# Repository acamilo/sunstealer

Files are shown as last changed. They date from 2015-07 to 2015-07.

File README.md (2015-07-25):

## SunStealer

Sunstealer is a 15 watt single color (rs485) networked LED strip built using a LT34781 driver and a PIC32MX110F016B. These strips are intended to be used to build larger LED panels with each strip covering a specific wavelength.

The goal is to be able to control the amount of light received by plants at each of these wavelengths and attempt to replicate some of the existing studies on type of light and it's affect on vegetative growth and fruiting.

There will be 5 variants of the strip each populated with LEDs targeting te following wavelengths (439,469,642,667,740) initially with the following ratios (1,1,2,2,1) This should make 1 105w LED light for hydro/aquaponics.

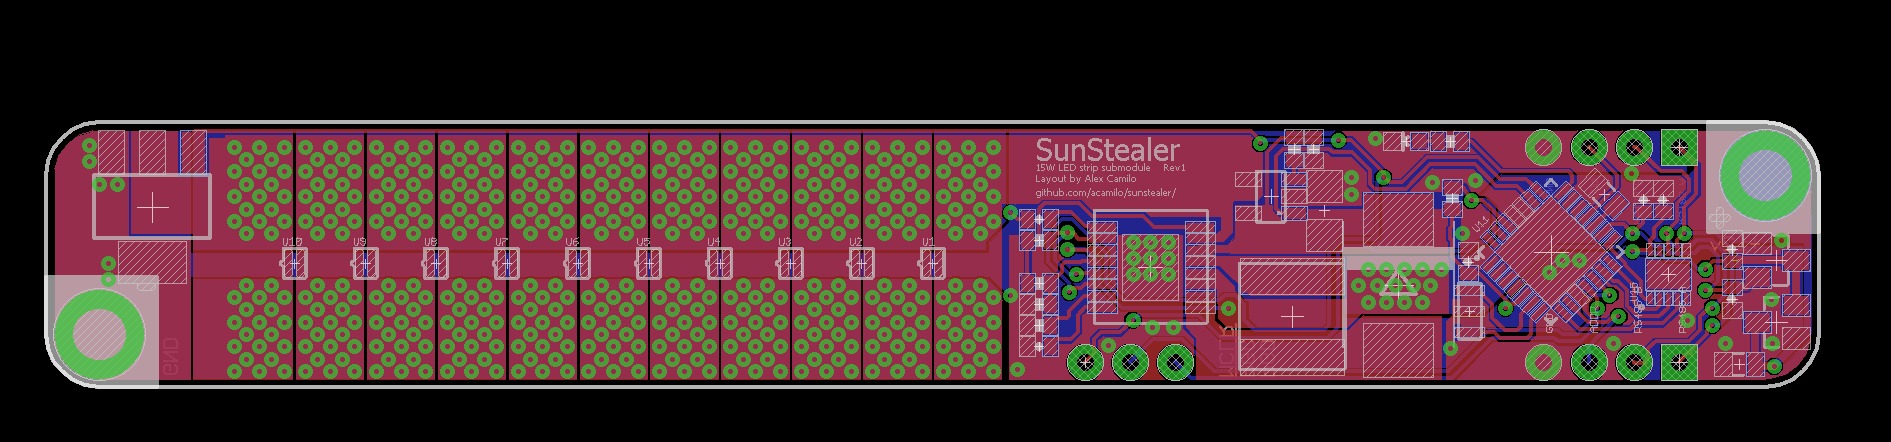
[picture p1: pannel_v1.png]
pcb


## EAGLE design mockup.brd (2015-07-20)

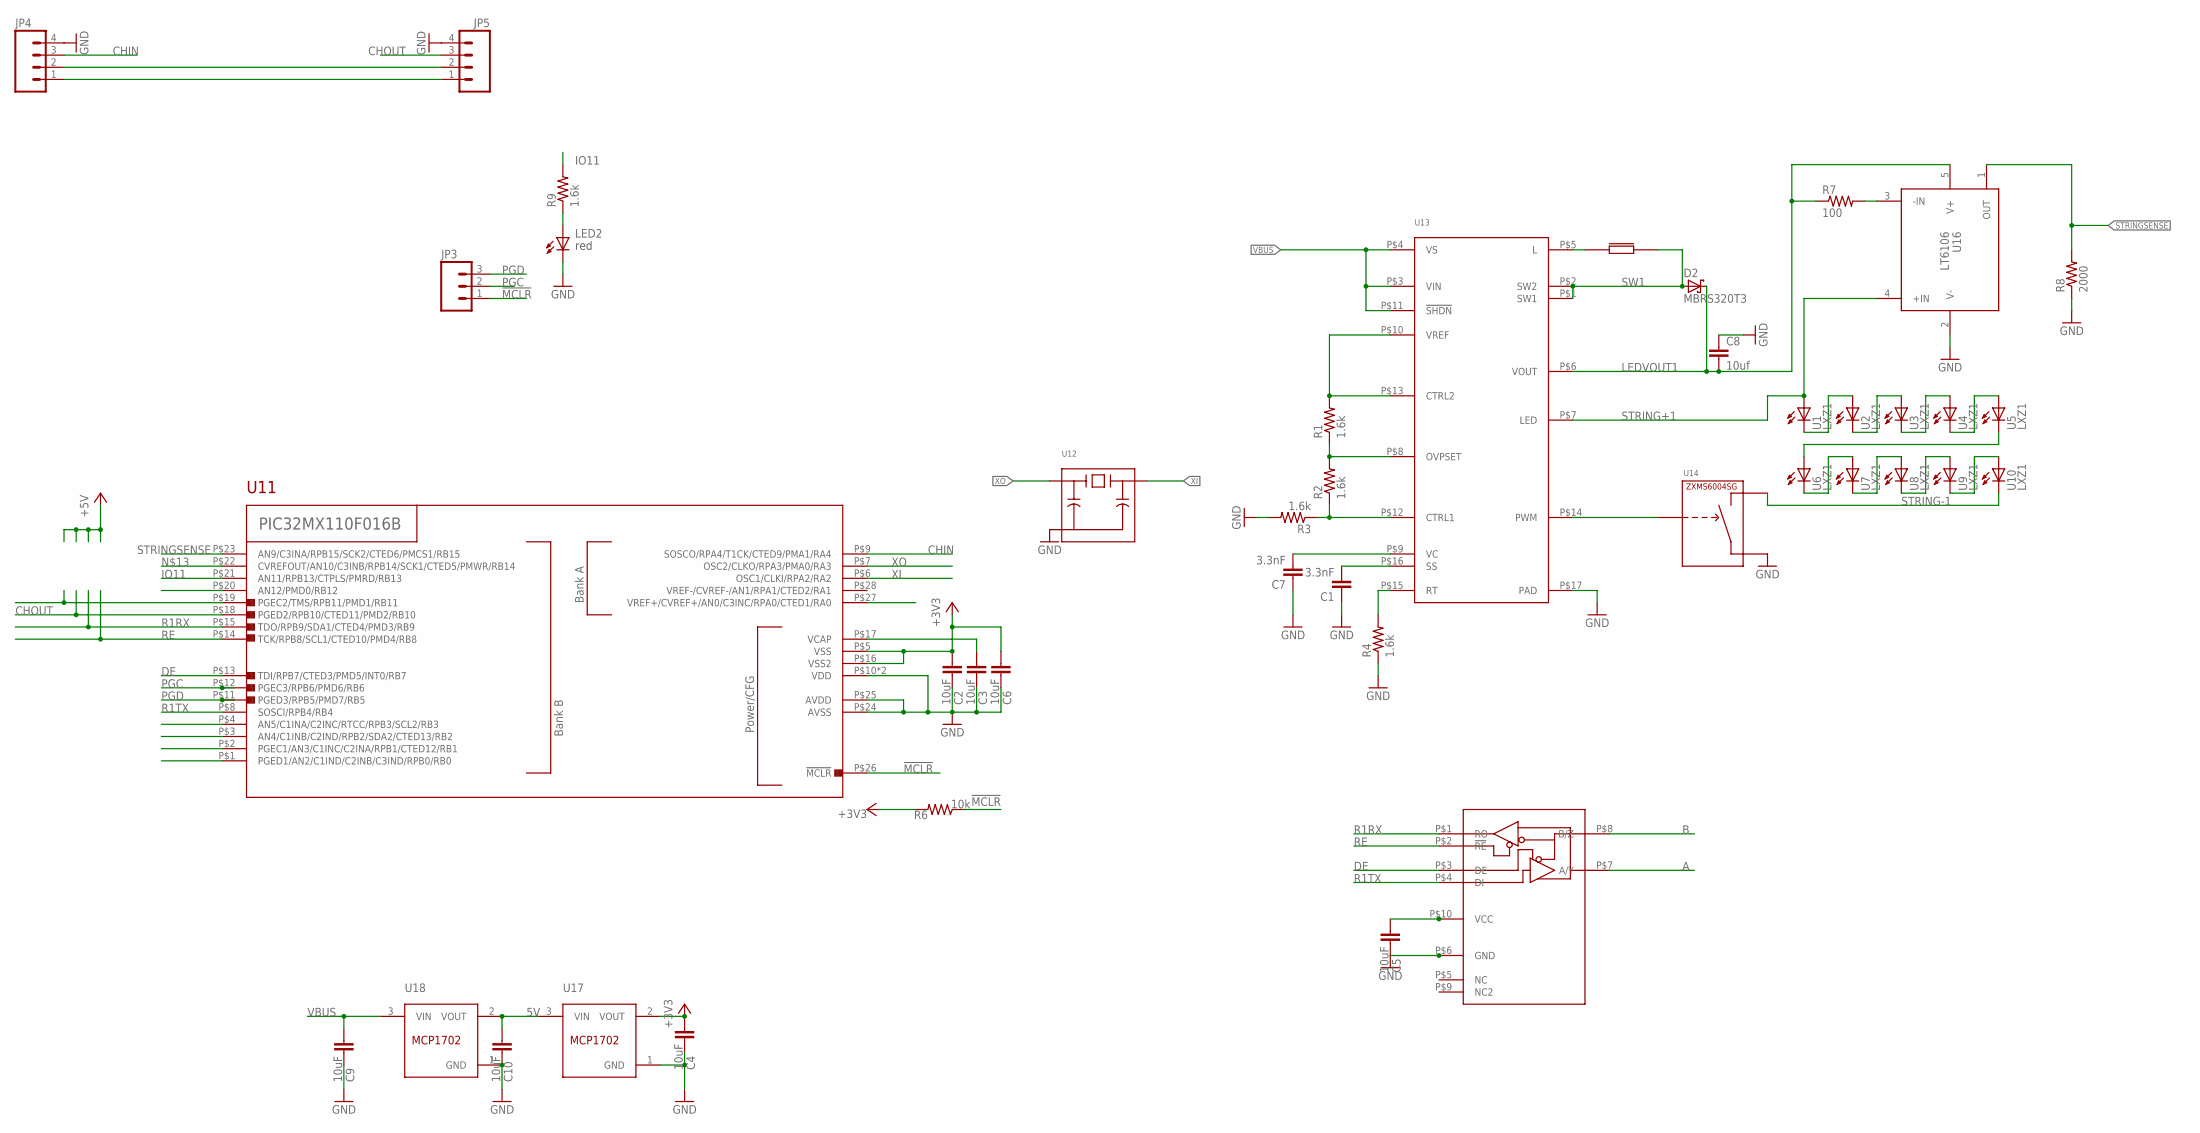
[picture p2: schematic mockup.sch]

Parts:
C1, C7: 3.3nF; 0402-CAP
C2, C4, C5, C6, C10: 10uF; 0402-CAP; PART# LMK212BJ106KG-T
C3, C9: 10uF; 0805; PART# LMK212BJ106KG-T
C8: 10uf; 1206
D2: MBRS320T3; SMC
JP3: M031X03_NO_SILK; 1X03_NO_SILK
JP4, JP5: M041X04_NO_SILK; 1X04_NO_SILK
LED2: LS L29K-G1J2-1-Z; LED-0603
R1, R2, R3, R4, R9: 1.6k; 0402-RES
R6: 10k; 0402-RES
R7: 100; 0402-RES
R8: 2000; 0402-RES
U1, U2, U3, U4, U5, U6, U7, U8, U9, U10: LXZ1
U11: PIC32MX110QFN; 28-QFN
U12: CSTCE
U13: 34781F; TSSOP16
U14: ZXMS6004SG; SOT223
U15: ISL3159E; DFN10
U16: LT6106; 5-LEAD-TSOT-23
U17, U18: MCP1702T; SOT23
U$27: 74404064068

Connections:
5V: C5.1, C10.1, U15.P$10 (VCC), U17.3 (VIN), U18.2 (VOUT)
!MCLR: JP3.1, R6.1, U11.P$26 (!MCLR)
+3V3: C2.1, C4.1, C6.1, R6.2, U11.P$5 (VSS), U11.P$16 (VSS2), U17.2 (VOUT)
A: JP4.1, JP5.1, U15.P$7 (A/Y)
B: JP4.2, JP5.2, U15.P$8 (B/Z)
CHIN: JP4.3, U11.P$9 (SOSCO/RPA4/T1CK/CTED9/PMA1/RA4)
CHOUT: JP5.3, U11.P$18 (PGED2/RPB10/CTED11/PMD2/RB10)
CONFIG: U11.P$27 (VREF+/CVREF+/AN0/C3INC/RPA0/CTED1/RA0)
DE: U11.P$13 (TDI/RPB7/CTED3/PMD5/INT0/RB7), U15.P$3 (DE)
GND: C1.1, C2.2, C3.2, C4.2, C5.2, C6.2, C7.1, C8.1, C9.2, C10.2, JP4.4, JP5.4, LED2.C, R3.2, R4.1, R8.1, U11.P$10 (VDD), U11.P$24 (AVSS), U11.P$25 (AVDD), U11.P$29 (VDD), U12.2, U13.P$17 (PAD), U14.3 (S), U14.4 (S), U15.P$6 (GND), U16.2 (V-), U17.1 (GND), U18.1 (GND)
IO4: U11.P$20 (AN12/PMD0/RB12)
IO6: U11.P$4 (AN5/C1INA/C2INC/RTCC/RPB3/SCL2/RB3)
IO7: U11.P$3 (AN4/C1INB/C2IND/RPB2/SDA2/CTED13/RB2)
IO8: U11.P$2 (PGEC1/AN3/C1INC/C2INA/RPB1/CTED12/RB1)
IO9: U11.P$1 (PGED1/AN2/C1IND/C2INB/C3IND/RPB0/RB0)
IO11: R9.2, U11.P$21 (AN11/RPB13/CTPLS/PMRD/RB13)
L1: U13.P$5 (L), U$27.P$1
LEDVOUT1: C8.2, D2.C, R7.1, U13.P$6 (VOUT), U16.5 (V+)
unnamed: LED2.A, R9.1
unnamed: R2.1, R3.1, U13.P$12 (CTRL1)
unnamed: R1.1, R2.2, U13.P$8 (OVPSET)
unnamed: C3.1, U11.P$17 (VCAP)
unnamed: R1.2, U13.P$10 (VREF), U13.P$13 (CTRL2)
unnamed: R4.2, U13.P$15 (RT)
unnamed: C7.2, U13.P$9 (VC)
unnamed: C1.2, U13.P$16 (SS)
unnamed: U11.P$22 (CVREFOUT/AN10/C3INB/RPB14/SCK1/CTED5/PM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), U13.P$14 (PWM), U14.1 (IN)
unnamed: U1.K (C), U2.A
unnamed: U2.K (C), U3.A
unnamed: U3.K (C), U4.A
unnamed: U4.K (C), U5.A
unnamed: U5.K (C), U6.A
unnamed: U6.K (C), U7.A
unnamed: U7.K (C), U8.A
unnamed: U8.K (C), U9.A
unnamed: U9.K (C), U10.A
unnamed: R7.2, U16.3 (-IN)
PGC: JP3.2, U11.P$12 (PGEC3/RPB6/PMD6/RB6)
PGD: JP3.3, U11.P$11 (PGED3/RPB5/PMD7/RB5)
R1RX: U11.P$15 (TDO/RPB9/SDA1/CTED4/PMD3/RB9), U15.P$1 (RO)
R1TX: U11.P$8 (SOSCI/RPB4/RB4), U15.P$4 (DI)
RE: U11.P$14 (TCK/RPB8/SCL1/CTED10/PMD4/RB8), U15.P$2 (!RE)
SERVO1: U11.P$19 (PGEC2/TMS/RPB11/PMD1/RB11)
STRING+1: U1.A, U13.P$7 (LED), U16.4 (+IN)
STRING-1: U10.K (C), U14.2 (D)
STRINGSENSE: R8.2, U11.P$23 (AN9/C3INA/RPB15/SCK2/CTED6/PMCS1/RB15), U16.1 (OUT)
SW1: D2.A, U13.P$1 (SW1), U13.P$2 (SW2), U$27.P$2
VBUS: C9.1, U13.P$3 (VIN), U13.P$4 (VS), U13.P$11 (!SHDN), U18.3 (VIN)
XI: U11.P$6 (OSC1/CLKI/RPA2/RA2), U12.3
XO: U11.P$7 (OSC2/CLKO/RPA3/PMA0/RA3), U12.1

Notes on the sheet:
red

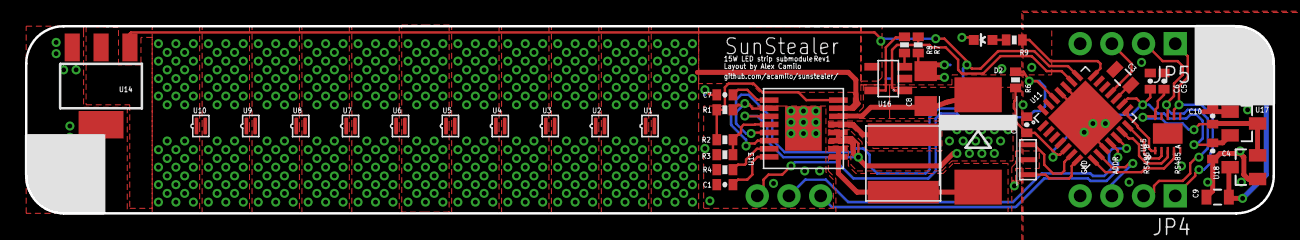
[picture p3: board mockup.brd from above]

Board: 2 copper layers, 100.0 x 15.0 mm, 42 parts (0 on the bottom side), 43 nets.

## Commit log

2015-07-20 board layout done
    [mockup.brd, mockup.sch]
2015-07-20 cleaned up silk
    [mockup.brd]

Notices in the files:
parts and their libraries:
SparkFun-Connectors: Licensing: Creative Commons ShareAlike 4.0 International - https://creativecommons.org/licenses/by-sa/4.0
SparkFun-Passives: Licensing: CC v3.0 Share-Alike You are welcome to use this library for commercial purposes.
